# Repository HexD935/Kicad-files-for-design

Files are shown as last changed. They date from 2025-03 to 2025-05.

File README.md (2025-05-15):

This is a repository for the design files of Jonathan Cohn and Simamkele Shologu's EEE3088F power subsystem.
_______________________________________________________________________________________________________
Problem Description:
_______________________________________________________________________________________________________
The goal is to create a robot that can solve a maze without external interference. This robot is known
as a Micro-Mouse(MM) and has become a somewhat infamous engineering example, with many trying
to make them solve the mazes faster and faster. A typical MM includes 4 major subsystems: power,
sensing, processor, and motherboard. This is being made for a university assignment where speed
does not matter. The specific part of the robot that has been assigned is the power subsystem which
will communicate with the MM’s microcontroller(uM) and various other parts to provide the required
currents and voltages to the required systems. As such the sensing, processor, and motherboard have
already been designed. The power system will need to interface with the motherboard that will connect
the rest of the subsystems and power the entire MM.
_______________________________________________________________________________________________________
Files Included:
_______________________________________________________________________________________________________
The KICAD design files are included in this repo which is the schematic and PCB files. There are also the 
history of edits et. 
_______________________________________________________________________________________________________
Usage:
_______________________________________________________________________________________________________
These files can be downloaded as a ZIP file which will need to be extracted into a local file. 
                       !!!!!THIS CAN ONLY BE RUN IN KICAD 9!!!!!!

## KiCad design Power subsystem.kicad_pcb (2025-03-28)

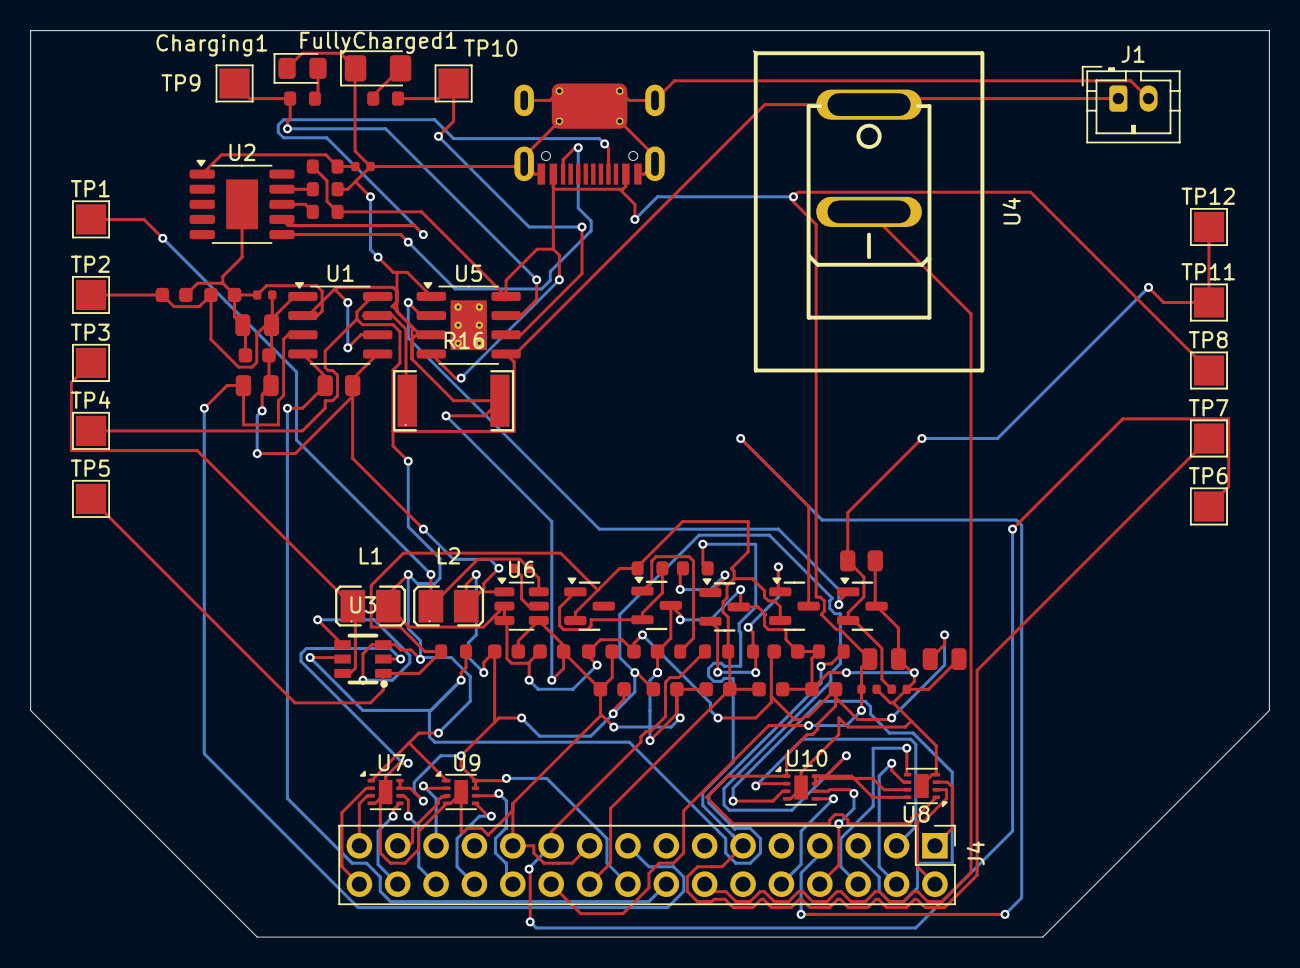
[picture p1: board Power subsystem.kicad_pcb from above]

Board: 2 copper layers, 82.0 x 60.0 mm, 70 parts (0 on the bottom side), 47 nets.

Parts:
C1: 4.7uF; C_0603
C2, C3, C12: 10uF; C_0805
C4, C6, C11: 100nF; C_0402
C5: 1uF; C_0402
C7, C8, C9, C10: 22uF; C_0603
C13, C14, C15, C16, C17, C18, C19, C20: 100nF; C_0603
Charging1: LED; LED_0805_2012Metric_Pad1.15x1.40mm_HandSolder
FullyCharged1: LED; LED_1206_3216Metric_Pad1.42x1.75mm_HandSolder
J1: Conn_01x02_Pin; JST_PH_B2B-PH-K_1x02_P2.00mm_Vertical
J3: Connector, USB-TYPE-C-16P; TYPE-C-SMD_HX-TYPE-C-16PIN
J4: Conn_02x16_Odd_Even; PinHeader_2x16_P2.54mm_Vertical
L1, L2: LQM2HPN2R2MG0L; L1008
Q1, Q4: AO3401A; Q_SOT-23
Q2, Q5: MMBT5551 200-300; Q_SOT-23
Q3: 2N7002; Q_SOT-23
R1: 1kΩ; R_0603
R2, R5, R10, R11: 10kΩ; R_0603
R3, R6: 4.7kΩ; R_0805
R4: 6.8kΩ; R_0603
R7, R8: 220Ω; R_0603
R9: 33kΩ; R_0603
R12: 470kΩ; R_0805
R13, R14: 470Ω; R_0603
R15: 100kΩ; R_0402
R16: MS122WJ050MT4E; R2512
TP1, TP2, TP3, TP4, TP5, TP6, TP7, TP8, TP9, TP10, TP11, TP12: TestPoint; TestPoint_Pad_2.0x2.0mm
U1: INA219AxD; SOIC-8_3.9x4.9mm_P1.27mm
U2: CH224K; SSOP-10-1EP_3.9x4.9mm_P1mm_EP2.1x3.3mm
U3: ETA1038S2G; SOT-23-6_L2.9-W1.6-P0.95-LS2.8-BR
U4: MR1-110-C5N-BBAA; SW-TH_MR1-110-C5N-BBAA
U5: TP4056-42-ESOP8; SOIC-8-1EP_3.9x4.9mm_P1.27mm_EP2.41x3.3mm_ThermalVias
U6: AP63203WU; TSOT-23-6
U7, U8, U9, U10: DRV8837; WSON-8-1EP_2x2mm_P0.5mm_EP0.9x1.6mm

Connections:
/3V3 Out: C2.2, C6.2, C9.2, C10.2, C13.1, C15.1, C17.1, C19.1, J4.18, L2.2, R3.2, R6.2, TP2.1, U1.1 (A1), U1.5 (VS), U6.1 (FB), U7.7 (~SLEEP), U7.8 (VCC), U8.7 (~SLEEP), U8.8 (VCC), U9.7 (~SLEEP), U9.8 (VCC), U10.7 (~SLEEP), U10.8 (VCC)
/5V Out: C7.1, C8.1, J4.20, Q1.2 (S), Q4.2 (S), R5.1, R9.1, R10.1, TP5.1, U3.1 (OUT)
/Battery: C1.2, C12.1, C14.1, C16.1, C18.1, C20.1, J1.1, L1.2, TP4.1, U1.8 (IN+), U3.3 (EN), U3.4 (IN), U4.1, U5.5 (BAT), U6.2 (EN), U6.3 (IN), U7.1 (VM), U8.1 (VM), U9.1 (VM), U10.1 (VM)
/CTRL_EXT_LOAD2: J4.7, Q4.3 (D)
/EXT_LOAD1_OUT: J4.21, R13.2, TP6.1
/EXT_LOAD2_OUT: J4.11, R14.2, TP7.1
/FAST_CHARGE_CTRL: Q3.2 (S), R12.1, R15.1, TP11.1, TP12.1
/HV: C3.1, C4.1, J3.A9B4 (VBUS), J3.B9A4 (VBUS), J4.22, R1.1, R2.1, TP8.1, U5.4 (V_{CC}), U5.8 (CE)
/I2C1_SCL: J4.16, R6.1, U1.4 (SCL)
/I2C1_SDA: J4.17, R3.1, U1.3 (SDA)
/MOTOR1_A_OUT: J4.32, U7.2 (OUT1)
/MOTOR1_B_OUT: J4.31, U7.3 (OUT2)
/MOTOR1_CTRL1: J4.28, U7.6 (IN1)
/MOTOR1_CTRL2: J4.30, U7.5 (IN2)
/MOTOR2_CTRL1: J4.4, U8.6 (IN1)
/MOTOR2_CTRL2: J4.6, U8.5 (IN2)
/MOTOR3_A_OUT: J4.27, U9.2 (OUT1)
/MOTOR3_B_OUT: J4.29, U9.3 (OUT2)
/MOTOR3_CTRL1: J4.24, U9.6 (IN1)
/MOTOR3_CTRL2: J4.26, U9.5 (IN2)
/MOTOR4_CTRL1: J4.8, U10.6 (IN1)
/MOTOR4_CTRL2: J4.10, U10.5 (IN2)
/Motor2_A_OUT: J4.2, U8.2 (OUT1)
/Motor2_B_OUT: J4.1, U8.3 (OUT2)
/Motor4_A_OUT: J4.3, U10.2 (OUT1)
/Motor4_B_OUT: J4.5, U10.3 (OUT2)
GND: C1.1, C2.1, C3.2, C4.2, C5.2, C6.1, C7.2, C8.2, C9.1, C10.1, C12.2, C13.2, C14.2, C15.2, C16.2, C17.2, C18.2, C19.2, C20.2, Charging1.1 (K), FullyCharged1.1 (K), J1.2, J3.A12B1 (GND), J3.B12A1 (GND), J3.S1 (SHIELD), J4.19, J4.23, Q2.3 (C), Q3.3 (D), Q5.3 (C), R4.2, R11.1, R12.2, R15.2, R16.2, U1.2 (A0), U1.6 (GND), U2.11 (GND), U3.2 (GND), U5.1 (TEMP), U5.3 (GND), U6.4 (GND), U7.4 (GND), U7.9 (GND), U8.4 (GND), U8.9 (GND), U9.4 (GND), U9.9 (GND), U10.4 (GND), U10.9 (GND)
unnamed: Charging1.2 (A), R8.2
unnamed: FullyCharged1.2 (A), R7.2
unnamed: J3.A5 (CC1), U2.7 (CC1)
unnamed: J3.B5 (CC2), U2.6 (CC2)
unnamed: J4.14, U4.2
unnamed: Q1.1 (G), Q2.2 (E), R5.2
unnamed: Q2.1 (B), R13.1
unnamed: Q3.1 (G), U5.2 (PROG)
unnamed: Q4.1 (G), Q5.2 (E), R10.2
unnamed: Q5.1 (B), R14.1
unnamed: R16.1, U1.7 (IN-)
unnamed: R4.1, U2.9 (CFG1)
unnamed: R2.2, U2.8 (VBUS)
unnamed: C5.1, R1.2, U2.1 (VDD)
unnamed: R9.2, R11.2, U3.5 (FB)
unnamed: L1.1, TP3.1, U3.6 (SW)
unnamed: R8.1, TP9.1, U5.7 (~CHRG)
unnamed: R7.1, TP10.1, U5.6 (~STDBY)
unnamed: C11.2, L2.1, TP1.1, U6.6 (BST)
unnamed: C11.1, U6.5 (SW)

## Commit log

2025-03-26 Update and rename Power subsystem (1).kicad_sch to Power subsystem.kicad_sch
    [Power subsystem .kicad_sch]
2025-03-26 Update and rename Power subsystem .kicad_sch to Power subsystem.kicad_sch
    [Power subsystem.kicad_sch]
2025-03-27 Update and rename Power subsystem (3).kicad_sch to Power subsystem.kicad_sch
    [Power subsysteM.kicad_sch]
2025-03-27 Update and rename Power subsysteM.kicad_sch to Power subsystem.kicad_sch
    [Power subsystem.kicad_sch]
